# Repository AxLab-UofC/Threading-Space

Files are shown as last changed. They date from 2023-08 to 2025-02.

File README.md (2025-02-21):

# What is Threading Space?
Threading Space is a kinetic sculpture that explores how spatial perception can be transformed by dynamically and geometrically reconfiguring physical lines of thread. As the threads in motion interact, they become a hypnotic medium for three-dimensional patterns. Through a physical installation and an interactive GUI, Threading Space invites the audience to explore the potential of using swarm robots and line elements to create, morph, and interact with space.

# How does Threading Space Work?
The Core loop of Threading Space is:
- The Animation System calculates the posistions of the toios
- Using `motorVelocityTarget`, a new velocity is sent to the toios based on their current and target posistions/velocities
- The Visualization and GUI is updated based on the new expected and actual locations of the toios

# Core Animation System
The core animation system accepts two kinds of sequences:
- Uninteractive sequences, which output a 2D or 3D set of points based on a time `t` in milliseconds. There are two types of uninteractive sequences:
  - Smooth Sequences, which continously move for a period of time
  - Discrete Sequences, which consist of a set of frames. The path-finding mechanism automatically generates a Discrete sequence to move between two sets of points.
- Interactive sequences, which output a 2D or 3D set of points based on input from the user.

Using an input function, the core animation system allows for
- Queuing animations
- Pausing and resuming animations
- If an sequence is supposed to tangle, the animation can be played in reverse to automatically untangle.

# Files
- Main
  - `Path_Planning`: Runs the command to generate the path planning
  - `keyMousePressed`: Manages any key presses or mouse events, including debug mode
  - `Threading_Space`: Manages the main loop and defines all user-defined variables (i.e. number of toios, toggle MSI mode, etc.)
 
- The Animation System
  - `Animation_Manager`: Controls the flow between different animations; manages wait times if MSI
  - `anim_interactive`: Manages the Interactive animations: Each interactive animation has a set of variables that the user can change in real-time
  - `Anim_Cylinder`: An Interactive animation that has a cylinder at the top and on the bottom
  - `Anim_Line`:  An Interactive animation that has a line at the top and on the bottom
  - `Anim_Screensaver`:  Contains all the non-interactive animations, including the MSI-specific animation

- Visualization
  - `visual`: Manages the 3D positions of the cubes in the visualization. This allows for the visualization of threading space to be synced or independant from their physical locations.
  - `display`: Contains the 3d components that make up the threading space visualization
  - `gui`: Manages the interactive aspects of the GUI, (i.e. the buttons)
 
- Toio and OSC Management:
  - `Cube`:  Stores the Cube class, which abstracts away the lower level communication with the toios
  - `pair`: Stores the Pair class, which manages pairs of cubes at once
  - `MotorTargetVel`: Stores the `motorTargetVelocity` command which will use PID to smoothly follow a moving target
  - `oscRecieve`: Manages all received OSC messages
  - `oscSend`: Sends OSC Messages
  - `Battery_Management`: Manages the battery-life record, saved as csv file (if in MSI mode)

# MSI mode
Screensaver will operate at designated time-intervals (not constantly) 
- Toggle MSI mode by msi=true, see `Threading_Space`
- Operation times defined by int[] playTimes, see also `Threading_Space`
- MSI screensaver behavior defined in `Anim_Screensaver`: msi_screensaver()
  - To alter the MSI-specific sequence, see sequences defined within
- MSI battery collection files are saved by name and date. 
  - Format: YYYYMMDD_x for x files made

The Full Laptop-Toio Documnentation can be found [here](https://github.com/AxLab-UofC/Laptop-TOIO)

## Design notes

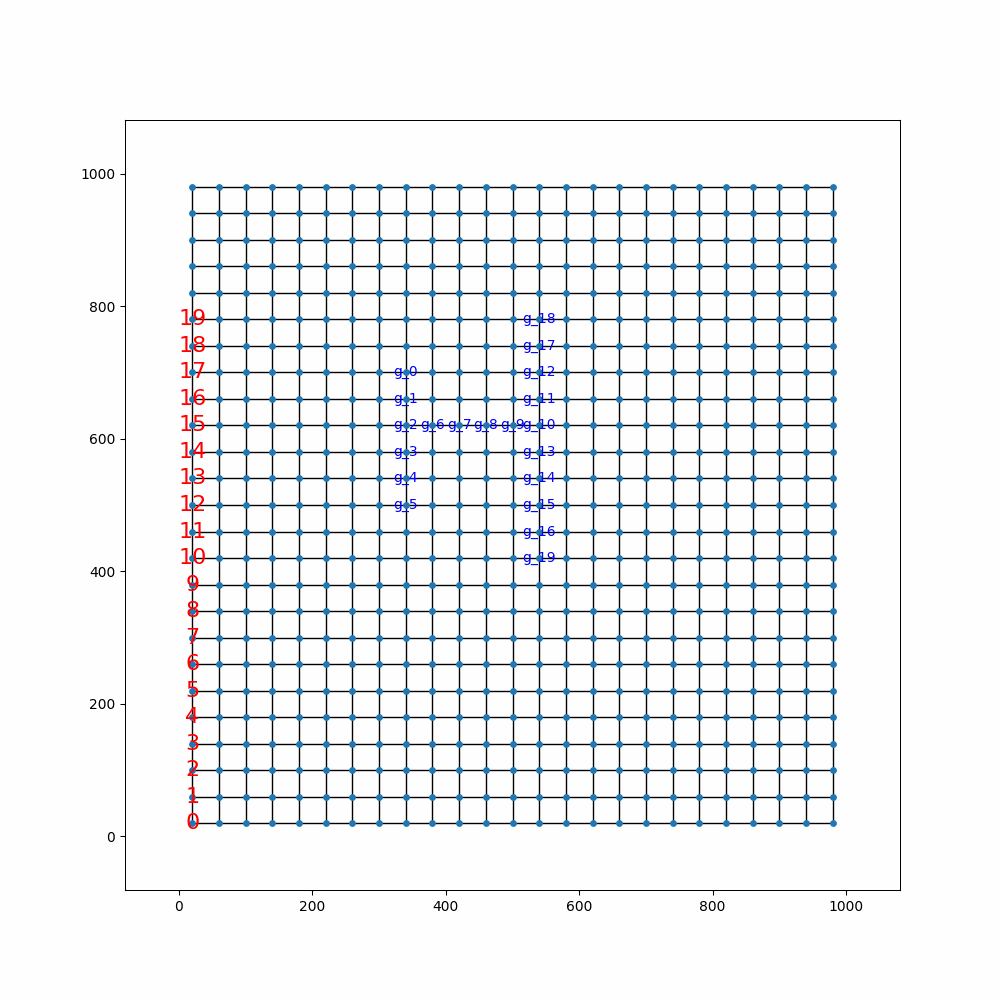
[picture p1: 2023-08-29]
general_planner_v1.0.1/toio_movement.gif

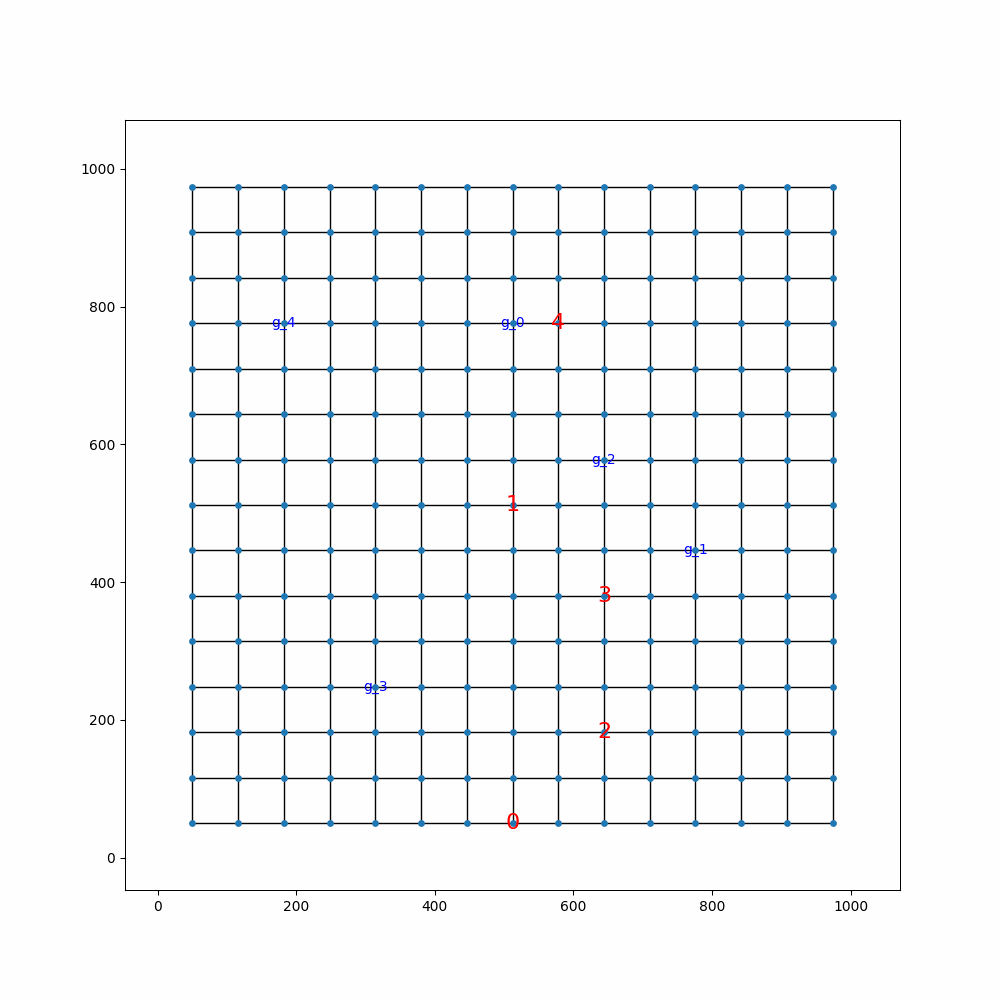
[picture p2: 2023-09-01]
general_planner_v1.0.1/movement.gif

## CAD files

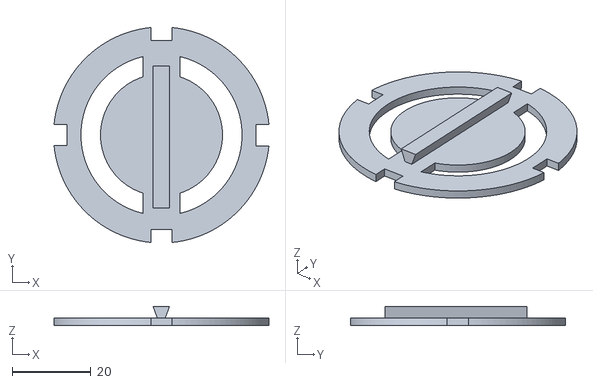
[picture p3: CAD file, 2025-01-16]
3D_print_files/final-lid-threading-space.stl
54.6 x 54.6 x 4.90

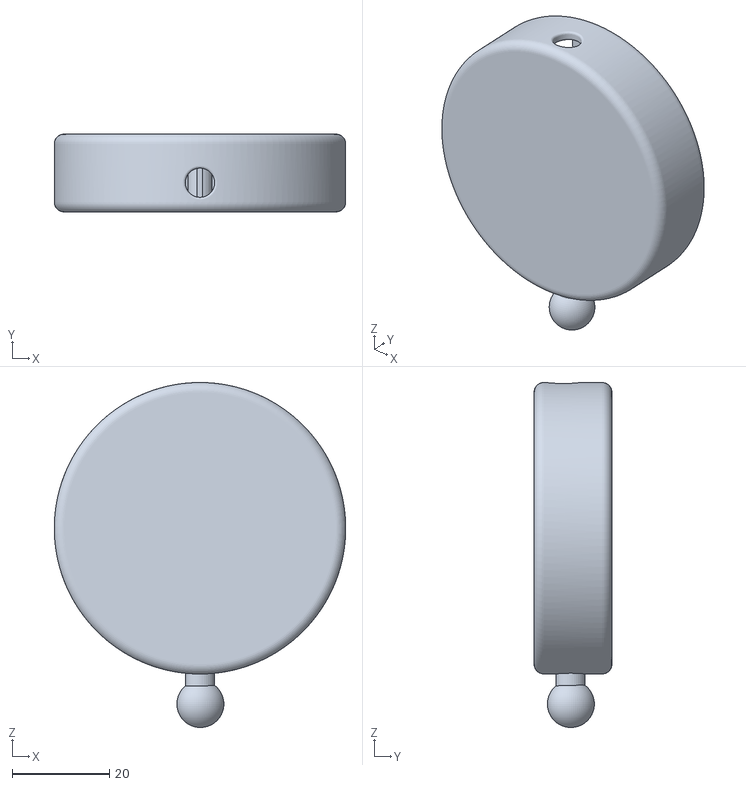
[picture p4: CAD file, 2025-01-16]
3D_print_files/reel_with_clasp-final-threading-space.stl
59.9 x 16.0 x 70.9

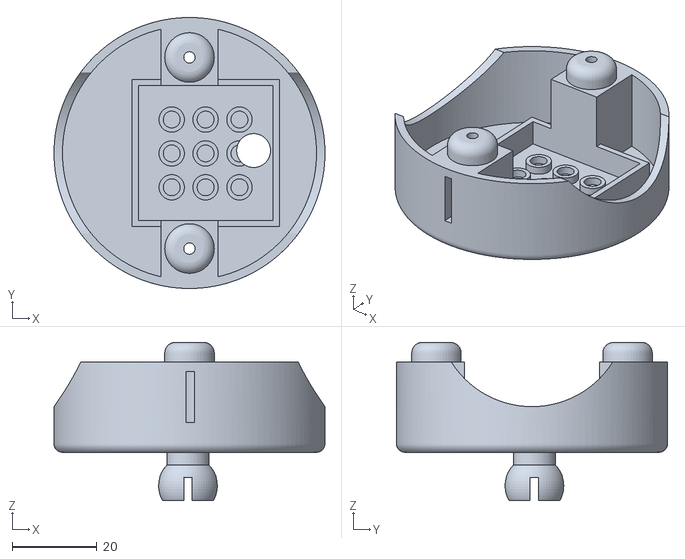
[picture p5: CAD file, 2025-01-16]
3D_print_files/toio_shell_-final-threading-space.stl
64.0 x 64.0 x 37.4

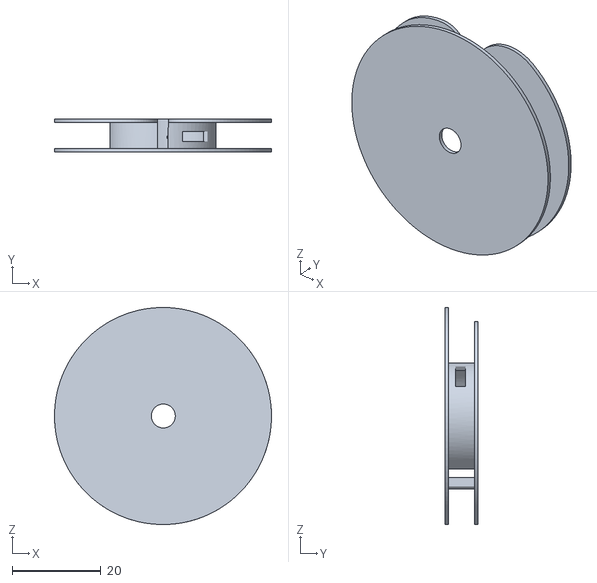
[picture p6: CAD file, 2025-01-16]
3D_print_files/scaled_inside_reel-with-rim-final-threading-space.stl
49.0 x 7.41 x 49.0

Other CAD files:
3D_print_files/fusion files/final-lid-threading-space.f3d
3D_print_files/fusion files/scaled_inside_reel-with-rim-final-threading-space.f3d

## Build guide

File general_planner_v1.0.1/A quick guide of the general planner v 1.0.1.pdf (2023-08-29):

# A quick guide of the general planner

v1.0.1 Update:
Now, the C++ planner can be run in the python notebook. No need to copy the map and agent files around.
The visualization code will now load the map and agent files that are the input to the C++ planner and visualize the planned paths.

The work is still ongoing. This is a quick guide about how to use the tool.
Required tools:
C++: the planner is a CMake project.
Python jupyter notebook or Google colab (an online python notebook environment)

How to use:
1. Generate maps and toio start and goal locations. This results in two files: a map file and an agent file.
The map file is a design of the "roads" in the planning space.
Example map file:

1000,1000,625,1200
0,20.0,20.0
1,20.0,60.0
2,20.0,100.0
3,20.0,140.0
4,20.0,180.0
5,20.0,220.0
6,20.0,260.0
7,20.0,300.0
8,20.0,340.0
9,20.0,380.0
623,980.0,940.0
624,980.0,980.0
0,1
0,25
1,2
1,26
2,3
2,27
3,4
3,28
4,5

The first line states: the x size of the planning space (1000), the y size of the planning space (1000), the number of vertices (waypoints that a toio can access) (625 vertices), the number of edges (1200).
Then the followed lines are the vertices (aka waypoints): vertex_id, x_coordinate, y_coordinate.
You can set the coordinates freely. But make sure that the waypoints are actually not blocked by any objects (e.g., walls).
Then the edge information lines: <vertex_id>, <connected_vertex_id>
For example, "0, 25" means the vertex with id 0 is connected to the vertex id 25.
The agent file states the start and the goal locations of toios:
For example,

The first line: <number_of_toios>
The followed lines: <toio_id>, <start_vertex_id>, <goal_vertex_id>
2. These two files are the input to the C++ planner.

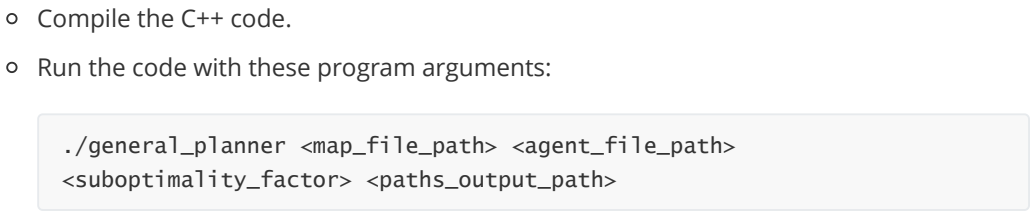
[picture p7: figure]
Compile the C++ code.; ./general_planner <map_file_path> <agent_file_path>; <suboptimality_factor> <paths_output_path>

Run the code with these program arguments:

<map_file_path>: the location of the map file.
<agent_file_path>: the location of the agent file.
<suboptimality_factor>: the parameter for focal search. You can simply put 5 in there. It trades the solution cost (the sum of path lengths) for runtime.
<paths_output_path>: where you want to output the path file.

20
0,0,217
1,1,216
2,2,215
3,3,214
4,4,213
5,5,212
6,6,240
7,7,265
8,8,290
9,9,315
10,10,340
11,11,341
12,12,342
13,13,339
14,14,338
15,15,337
16,16,336
17,17,343
18,18,344
19,19,335

3. Get the path file. The path file states the movements of toios in coordinates.

20,20,0 60,20,0 100,20,0 140,20,0 180,20,0 220,20,0 260,20,0 260,60,0 260,100,0 260,140,0 260,180,0 260,220,0 260,260,0 260,300,0 260,340,0 260,380,0 260,420,0 260,460,0 260,500,0 260,540,0 260,580,0 260,620,0 260,660,0 300,660,0 300,700,0 340,700,0
20,60,0 60,60,0 100,60,0 140,60,0 180,60,0 220,60,0 260,60,0 260,100,0 260,140,0 260,180,0 260,220,0 260,260,0 260,300,0 260,340,0 260,380,0 260,420,0 260,460,0 260,500,0 260,540,0 260,580,0 260,620,0 300,620,0 300,660,0 340,660,0
20,100,0 60,100,0 100,100,0 140,100,0 180,100,0 220,100,0 260,100,0 260,140,0 260,180,0 260,220,0 260,260,0 260,300,0 260,340,0 260,380,0 260,420,0 260,460,0 260,500,0 260,540,0 260,580,0 300,580,0 300,620,0 340,620,0
20,140,0 60,140,0 100,140,0 140,140,0 180,140,0 220,140,0 260,140,0 260,180,0 260,220,0 260,260,0 260,300,0 260,340,0 260,380,0 260,420,0 260,460,0 260,500,0 260,540,0 300,540,0 300,580,0 340,580,0
20,180,0 60,180,0 100,180,0 140,180,0 180,180,0 220,180,0 260,180,0 260,220,0 260,260,0 260,300,0 260,340,0 260,380,0 260,420,0 260,460,0 260,500,0 300,500,0 300,540,0 340,540,0
20,220,0 60,220,0 100,220,0 140,220,0 180,220,0 220,220,0 260,220,0 300,220,0 340,220,0 340,260,0 340,300,0 340,340,0 340,380,0 340,420,0 340,460,0 340,500,0
20,260,0 60,260,0 100,260,0 140,260,0 180,260,0 220,260,0 260,260,0 300,260,0 340,260,0 380,260,0 380,300,0 380,340,0 380,380,0 380,420,0 380,460,0 380,500,0 380,540,0 380,580,0 380,620,0
20,300,0 60,300,0 100,300,0 140,300,0 180,300,0 220,300,0 260,300,0 300,300,0 340,300,0 380,300,0 420,300,0 420,340,0 420,380,0 420,420,0 420,460,0 420,500,0 420,540,0 420,580,0 420,620,0
20,340,0 60,340,0 100,340,0 140,340,0 180,340,0 220,340,0 260,340,0 300,340,0 300,380,0 300,420,0 340,420,0 380,420,0 380,460,0 380,500,0 380,540,0 380,580,0 420,580,0 460,580,0 460,620,0
20,380,0 60,380,0 100,380,0 140,380,0 180,380,0 220,380,0 260,380,0 300,380,0 300,420,0 300,460,0 340,460,0 380,460,0 420,460,0 420,500,0 420,540,0 460,540,0 500,540,0 500,580,0 500,620,0
20,420,0 60,420,0 100,420,0 140,420,0 180,420,0 220,420,0 260,420,0 300,420,0 300,460,0 300,500,0 340,500,0 380,500,0 420,500,0 420,540,0 420,580,0 460,580,0 500,580,0 500,620,0 540,620,0
20,460,0 60,460,0 100,460,0 140,460,0 180,460,0 220,460,0 260,460,0 300,460,0 300,500,0 300,540,0 340,540,0 380,540,0 380,580,0 420,580,0 460,580,0 500,580,0 500,620,0 540,620,0 540,660,0
20,500,0 60,500,0 100,500,0 140,500,0 180,500,0 220,500,0 260,500,0 300,500,0 340,500,0 380,500,0 420,500,0 460,500,0 500,500,0 500,540,0 500,580,0 500,620,0 540,620,0 540,660,0 540,700,0
20,540,0 60,540,0 100,540,0 140,540,0 180,540,0 220,540,0 260,540,0 300,540,0 340,540,0 380,540,0 420,540,0 460,540,0 500,540,0 500,580,0 500,620,0 540,620,0 540,580,0
20,580,0 60,580,0 100,580,0 140,580,0 180,580,0 220,580,0 260,580,0 300,580,0 340,580,0 380,580,0 420,580,0 460,580,0 500,580,0 540,580,0 540,540,0
20,620,0 60,620,0 100,620,0 140,620,0 180,620,0 220,620,0 260,620,0 300,620,0 340,620,0 380,620,0 420,620,0 460,620,0 500,620,0 540,620,0 540,580,0 580,580,0 580,540,0 580,500,0 540,500,0
20,660,0 60,660,0 100,660,0 140,660,0 180,660,0 220,660,0 260,660,0 300,660,0 340,660,0 380,660,0 420,660,0 460,660,0 460,620,0 460,580,0 460,540,0 500,540,0 500,500,0 540,500,0 540,460,0

Each line is the movement of a toio in coordinates (x,y,z). The z-axis movement is not implemented at this moment.
The toio stays at the goal location once it reaches the location.

# Walkthrough of an example:

1. Open the python notebook ("map_generator_and_visulization.ipynb")
2. Run the library import block

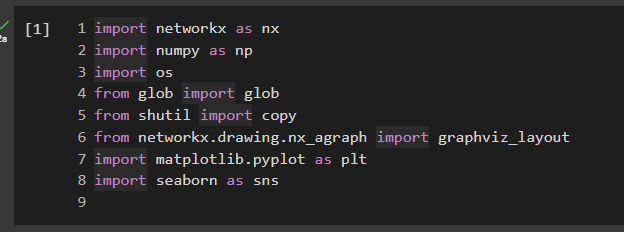
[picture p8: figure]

3. Then move on to the code for generating a grid general map.

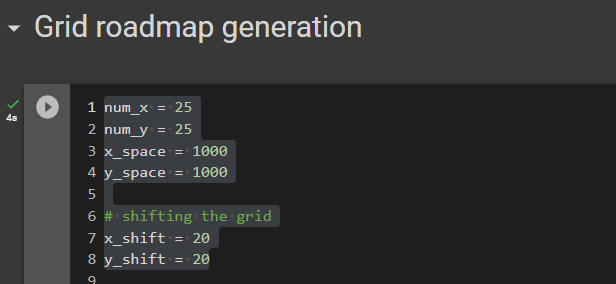
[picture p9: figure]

You only need to change these parameters. num_x: how many vertices are in the x-axis num_y: how many vertices are in the y-axis x_space: the x size of the map

20,700,0 60,700,0 100,700,0 140,700,0 180,700,0 220,700,0 260,700,0 300,700,0 340,700,0 380,700,0 420,700,0 460,700,0 500,700,0 540,700,0 540,740,0
20,740,0 60,740,0 100,740,0 140,740,0 180,740,0 220,740,0 260,740,0 300,740,0 340,740,0 380,740,0 420,740,0 460,740,0 500,740,0 540,740,0 540,780,0
20,780,0 60,780,0 100,780,0 140,780,0 180,780,0 220,780,0 260,780,0 300,780,0 300,740,0 300,700,0 340,700,0 380,700,0 420,700,0 460,700,0 460,660,0 460,620,0 460,580,0 460,540,0 500,540,0 500,500,0 500,460,0 500,420,0 540,420,0 y_space: the y size of the map
x_shift: it shifts the x coordinates of all vertices. y_shift: it shifts the y coordinates of all vertices.

Run the code, and you will see this picture output.

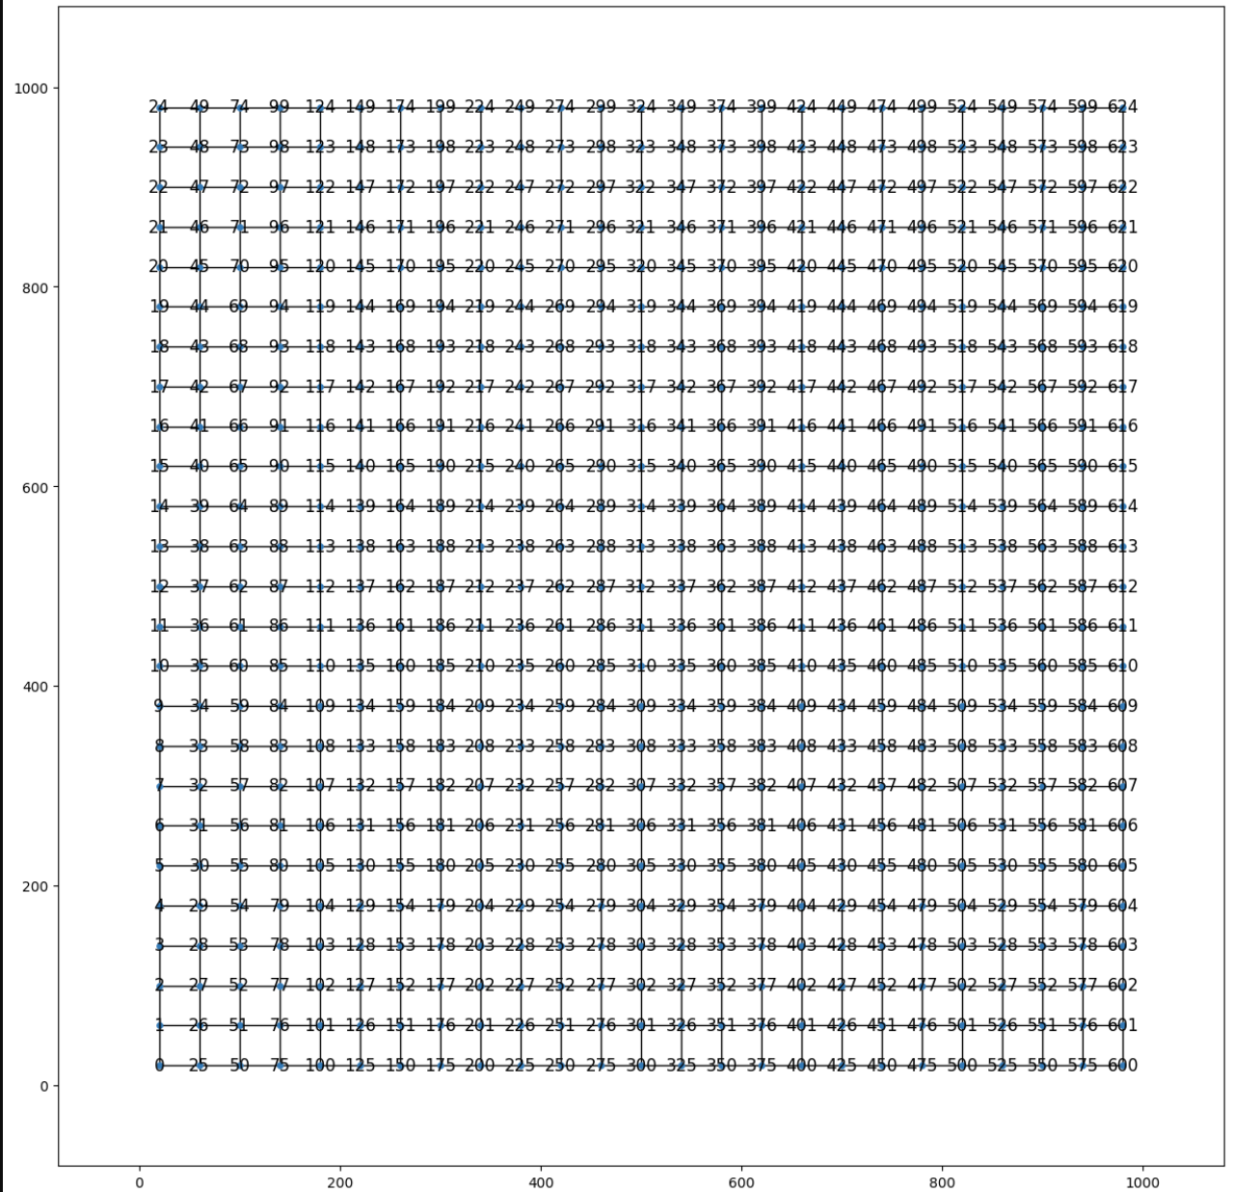
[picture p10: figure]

This is the grid "roadmap" generated by the code. Each vertex is the waypoint where the toio can be on, and each vertex is labelled with its vertex id.
The display of the vertex id can be helpful, if you want to write down the start and goal locations of toios mannually.

After running this block of code, it generates a map file "grid_map_x_x_x.txt" in the "toio_map_example" folder.
This is the map file that you need for using the C++ planner.
4. Generate an agent file.
This block of code generates one agent file with random start and goal locations.

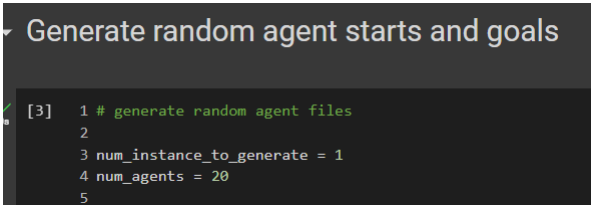
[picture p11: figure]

num_instance_to_generate: how many agent files will be generated. num_agents: how many toios are used.

You can use this block of code to generate a customized agent file.

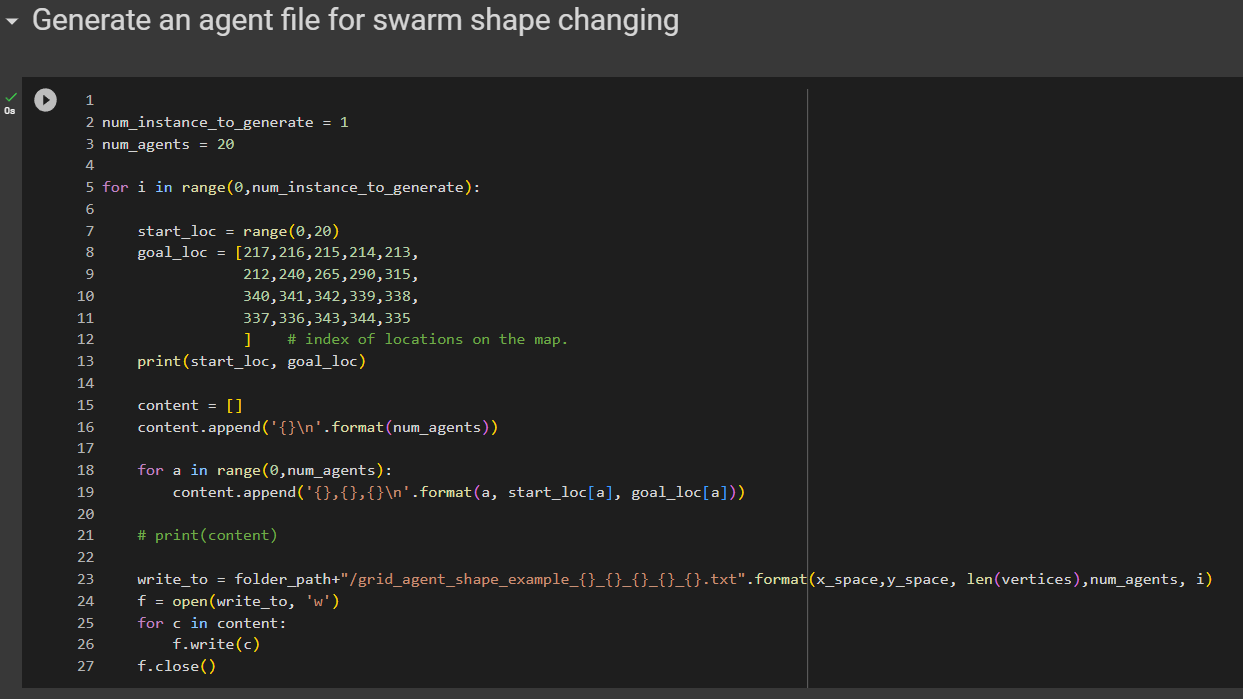
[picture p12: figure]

start_loc (line 7): the start vertex id for each agent.

goal_loc (line 8): the goal vertex id for each agent.
You can look at the map image generated in the previous step to pick the start and goal locations.
write_to (line 23): the path to the agent file. In this case, you will find an agent file in the "toio_map_examples" folder.
5. Compile the C++ planner and go to this block.

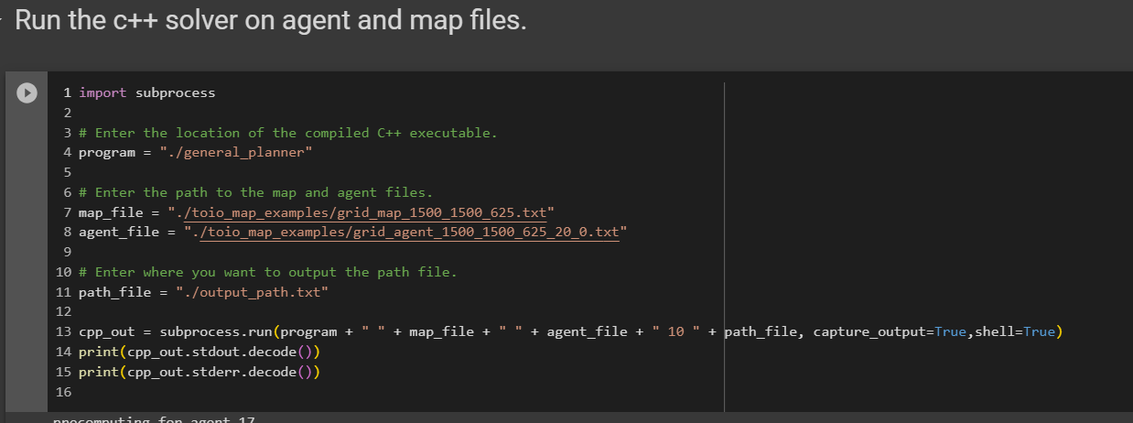
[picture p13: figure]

program: enter the path to the compiled C++ planner executable. map_file: which map file you want to load for planning. agent_file: which agent file you want to load for planning. path_file: where to output the result paths.

You can run the planner by just running this block of code.

6. Then just run the visualization code.
Now the visualization code will visualize the map and the movements that are just planned by the C++ planner.
The code reads the paths that are stored in "map_file", "agent_file", and "path_file" in the running C++ planner code block (the inputs to the planner and the output from the planner.).

Example movement:
If this git doesn't move in this document, check toio_movement.gif in the folder.


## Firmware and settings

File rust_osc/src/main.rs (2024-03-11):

extern crate getopts;
use btleplug::api::CharPropFlags;
use btleplug::api::{
    Central, CentralEvent, Characteristic, Manager as _, Peripheral, ScanFilter, WriteType,
};
use getopts::Options;

use btleplug::platform::Manager;
use futures::stream::StreamExt;
use rosc::encoder;
use rosc::{OscMessage, OscPacket, OscType};
use std::collections::HashMap;
use std::error::Error;
use std::sync::{Arc, Mutex};
use std::time::Duration;
use std::{env, net::SocketAddr};
use tokio::time;
use tokio::{net::UdpSocket, sync::mpsc};
use uuid::Uuid;

//#[macro_use]
extern crate log;

//characteristic of interest
const TOIO_SERVICE_UUID:            Uuid = Uuid::from_u128(0x10B20100_5B3B_4571_9508_CF3EFCD7BBAE);
const POSITION_CHARACTERISTIC_UUID: Uuid = Uuid::from_u128(0x10B20101_5B3B_4571_9508_CF3EFCD7BBAE);
const MOTOR_CHARACTERISTIC_UUID:    Uuid = Uuid::from_u128(0x10B20102_5B3B_4571_9508_CF3EFCD7BBAE);
const LIGHT_CHARACTERISTIC_UUID:    Uuid = Uuid::from_u128(0x10B20103_5B3B_4571_9508_CF3EFCD7BBAE);
const SOUND_CHARACTERISTIC_UUID:    Uuid = Uuid::from_u128(0x10B20104_5B3B_4571_9508_CF3EFCD7BBAE);
const MOTION_CHARACTERISTIC_UUID:   Uuid = Uuid::from_u128(0x10B20106_5B3B_4571_9508_CF3EFCD7BBAE);
const BUTTON_CHARACTERISTIC_UUID:   Uuid = Uuid::from_u128(0x10B20107_5B3B_4571_9508_CF3EFCD7BBAE);
const BATTERY_CHARACTERISTIC_UUID:  Uuid = Uuid::from_u128(0x10B20108_5B3B_4571_9508_CF3EFCD7BBAE);

fn print_usage(program: &str, opts: Options) {
    let brief = format!("Usage: {} FILE [options]", program);
    print!("{}", opts.usage(&brief));
}

fn print_toio_connected(toio_connected: i32){
    if toio_connected == 1 {println!("1 peripheral connected");}
    else {println!("{} peripherals connected", toio_connected);}
}

fn return_toio_id(name: &str) -> &str{
    //list of toio ids
    const IDARR : [&str; 193] = [
        "Individual ID",  //TOIO Num
        "0",  // #1
        "j1c",  // #2
        "r81",  // #3
        "26E",  // #4
        "76t",  // #5
        "broken",  // #6
        "k5k",  // #7
        "h41",  // #8
        "0",  // #9
        "0",  // #10
        "0",  // #11
        "Q3A",  // #12
        "03a",  // #13
        "0",  // #14
        "K0m",  // #15
        "0",  // #16
        "0",  // #17
        "p8B",  // #18
        "91B",  // #19
        "p75",  // #20
        "G1E",  // #21
        "k2L",  // #22
        "b5p",  // #23
        "J6C",  // #24
        "0",  // #25
        "b8T",  // #26
        "b6A",  // #27
        "01c",  // #28
        "0",  // #29
        "0",  // #30
        "E2N",  // #31
        "G7t",  // #32
        "L6T",  // #33
        "C0E",  // #34
        "t79",  // #35
        "J6k",  // #36
        "d6f",  // #37
        "0",  // #38
        "M75",  // #39
        "310",  // #40
        "M5p",  // #41
        "A4a",  // #42
        "M9J",  // #43
        "i01",  // #44
        "T5m",  // #45
        "j1G",  // #46
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
    ];
    match name.parse::<i32>() {
        Ok(n) => {
            let name = IDARR[n as usize];
            return name;
        },
        Err(_e) => {
            panic!("Error while reading the names");
        }
      }
}                

#[tokio::main]
async fn main() -> Result<(), Box<dyn Error>> {
    env_logger::init();

    let mut toio_connected = 0;
    let mut verbose = false;
    let mut search = false;
    let mut ordered = false;
    let mut ordernum = 0;

    //read command line arguments
    let args: Vec<String> = env::args().collect();
    let program = args[0].clone();

    let mut opts = Options::new();
    opts.optopt("p", "port", "set receiving port", "PORT_NUMBER");
    opts.optopt("r", "remote", "set remote port", "IP:PORT_NUMBER");
    opts.optopt("i", "host_id", "set host id number", "ID_NUMBER");
    opts.optopt("n", "names", "connect to those cubes only", "AAA,BBB,CCC");
    opts.optopt("a", "axlab_id", "connect to those cubes only (#1, #2, #3)", "1,2,3");
    opts.optflag("h", "help", "print this help menu");
    opts.optflag("v", "verbose", "print more connection details");
    opts.optflag("s", "search", "search for toios without specifying IDs");
    opts.optflag("o", "ordered", "search for toios in order of IDs");

    let matches = match opts.parse(&args[1..]) {
        Ok(m) => { m }
        Err(f) => { panic!("{}",f.to_string())}
    };
    if matches.opt_present("h") {
        print_usage(&program, opts);
        return Ok(());
    }
    if matches.opt_present("v") {
        verbose = true;
    }
    if matches.opt_present("s") {
        search = true;
    }

    let port_number = matches.opt_str("p").unwrap_or("3334".to_string());
    let listening_address = format!("0.0.0.0:{}", port_number);

    //this will be filled with the names to connect to *if needed*
    let possible_names = {
        let mut res = Vec::new();
        match matches.opt_str("n") {
            Some(names) => {
                for part in names.split(",") {
                    if part.len() == 3 {
                        res.push(format!("toio Core Cube-{}", part));
                    } else {
                        panic!("Error while reading the names");
                    }
                }
            },
            None => {}
        }
        match matches.opt_str("a") {
            Some(names) => {
                for part in names.split(",") {
                    res.push(format!("toio Core Cube-{}", return_toio_id(part)));
                }
            },
            None => {}
        }

        if !search && res.len() == 0 {
            panic!("Toio IDs must be specified unless in search mode");
        }

        if res.len() > 0 {
            ordernum = res.len();
            Some(res)
        } else {
            None
        }
    };

    if matches.opt_present("o") {
        ordered = true;
        ordernum = 1;
    }

    //the ID/addresses of the cubes
    //let addresses: Arc<Mutex<Vec<BDAddr>>> = Arc::new(Mutex::new(Vec::new()));
    let uuids: Arc<Mutex<Vec<btleplug::platform::PeripheralId>>> = Arc::new(Mutex::new(Vec::new()));
    let senders: Arc<Mutex<HashMap<btleplug::platform::PeripheralId, mpsc::Sender<OscMessage>>>> =
        Arc::new(Mutex::new(HashMap::new()));

    //OSC listening on port 3334
    let sock = UdpSocket::bind((listening_address).parse::<SocketAddr>().unwrap()).await?;
    println!("OSC listening on port {}", port_number);

    let r = Arc::new(sock);
    let s = r.clone();
    let (tx, mut rx) = mpsc::channel::<(Vec<u8>, SocketAddr)>(1_000);

    //Where to send packets
    let remote = matches.opt_str("r").unwrap_or("127.0.0.1:3333".to_string());
    let remote_read = remote.parse::<SocketAddr>();
    let remote_addr = if remote_read.is_ok() {
        remote_read.unwrap()
    } else {
        eprintln!(
            "Remote address {} is wrongly formatted, use IP:PORT (127.0.0.1:3333)",
            remote
        );
        return Ok(());
    };

    let host_id = matches
        .opt_str("i")
        .unwrap_or("0".to_string())
        .parse::<i32>()
        .unwrap_or(0);
    println!(
        "Sending messages to {} prefixed by {}",
        remote_addr, host_id
    );

    //Send OSC
    tokio::spawn(async move {
        //just one channel
        while let Some((bytes, addr)) = rx.recv().await {
            s.send_to(&bytes, &addr).await.unwrap();
        }
    });

    //Receive OSC
    let mut buf = [0; 1024];
    //let addresses2 = addresses.clone();
    let uuids2 = uuids.clone();
    let senders2 = senders.clone();

    tokio::spawn(async move {
        while let Ok((len, addr)) = r.recv_from(&mut buf).await {
            println!("{:?} bytes received from {:?}", len, addr);
            let packet = rosc::decoder::decode(&buf[..len]).unwrap();
            match packet {
                OscPacket::Message(msg) => {
                    if msg.args.len() > 0 {
                        let mut marg = 0;
                        if let OscType::Int(i) = msg.args[0] {
                            marg = i;
                        }
                        println!("Got a message for {}", marg);

                        // find the address
                        let maybe_uuid = {
                            let storage_uuid = uuids2.lock().unwrap();
                            if storage_uuid.len() > marg as usize {
                                Some(storage_uuid[marg as usize].clone())
                            } else {
                                None
                            }
                        };
                        if let Some(uuid) = maybe_uuid {
                            //try to get the channel and not breaking everything
                            let sender = {
                                let sends = senders2.lock().unwrap();
                                sends.get(&uuid).map(|p| p.clone())
                                //we drop the lock here because we *clone*
                            };
                            if let Some(channel) = sender {
                                println!("Sending to...");
                                channel.send(msg).await.unwrap();
                            }
                        }
                    }
                }
                OscPacket::Bundle(bundle) => {
                    println!("OSC Bundle: {:?}", bundle);
                }
            }
        }
    });

    let manager = Manager::new().await?;

    println!("Found Manager: {:?}", manager);
    // get the first bluetooth adapter
    // connect to the adapter
    let adapters = manager.adapters().await.unwrap();
    println!("Found Adapter: ");
    for adapter in adapters.iter() {
        println!("Found Adapter: {}", adapter.adapter_info().await?);
    }

    let central = adapters.into_iter().nth(0).unwrap();

    //get the events from the central
    let mut events = central.events().await?;

    // start scanning for devices
    central
        .start_scan(ScanFilter {
            services: vec![TOIO_SERVICE_UUID],
        })
        .await?;

    if verbose {
        println!("Scanning for BTLE events on {:?}...",central);
    }
    else {
        println!("Scanning for BTLE events...");
    }  

    //Scan all the time
    while let Some(event) = events.next().await {
        //println!("event... {:?}", event);
        let mut device_candidate: Option<btleplug::platform::PeripheralId> = None;
        //Sometimes we miss the discovered event, so react on the DeviceUpdated as well
        match event {
            CentralEvent::DeviceUpdated(bd_addr) => {
                device_candidate = Some(bd_addr);
            }
            CentralEvent::DeviceDiscovered(bd_addr) => {
                device_candidate = Some(bd_addr);
            }
            CentralEvent::DeviceDisconnected(bd_addr) => {
                println!("DeviceDisconnected: {:?}", bd_addr);
                toio_connected -= 1;
                print_toio_connected(toio_connected);
            }
            _ => {}
        }

        
        //
        if let Some(bd_addr) = device_candidate {
            let peripheral = central.peripheral(&bd_addr).await.unwrap();

            let properties = peripheral.properties().await?.unwrap();
            let local_name = properties.local_name.unwrap_or("".to_string());

            let services = properties.services;
            let should_connect = if let Some(names) = &possible_names {
                if ordernum > names.len() {
                    ordernum -= 1;
                }
                names[0 ..ordernum].contains(&local_name)
            } else {
                services.contains(&TOIO_SERVICE_UUID)
            };


            //if (services.contains(&TOIO_SERVICE_UUID)) || possible_names.contains(&local_name)  {
            if should_connect {
                if ordered {
                    ordernum += 1;
                }
                //we kave a toio cube!
                let tx3 = tx.clone();
                if !(peripheral.is_connected().await?) {
                    println!("Device Connected: {}", local_name);
                    toio_connected  += 1;
                    print_toio_connected(toio_connected);

                    // Connect if we aren't already connected.
                    if let Err(err) = peripheral.connect().await {
                        eprintln!("Error connecting to peripheral, skipping: {}", err);
                        continue;
                    }
                    time::sleep(Duration::from_millis(200)).await;
                    // We should be connected now
                    let peripheral_id = peripheral.id();
                    if verbose {
                        println!("connecting with Peripheral ID: {:?}", peripheral_id);
                    }

                    //find the id for this cube
                    //let mut addr = addresses.lock().unwrap();
                    let mut storage_uuid = uuids.lock().unwrap();

                    //do we already know that address?
                    let id = if let Some(index) =
                        storage_uuid.iter().position(|a| a == &peripheral_id)
                    {
                        index
                    } else {
                        //no, add it to the list
                        storage_uuid.push(peripheral_id.clone());
                        storage_uuid.len() - 1
                    };
                    //get rid of the mutex lock
                    drop(storage_uuid);
                    //println!("Connecting to Cube {} address is {}", id, address);

                    //creating the channels
                    let (tx, mut rx) = mpsc::channel::<OscMessage>(1_000);
                    //saving one end to allow to receive OSC
                    let mut sends = senders.lock().unwrap();
                    sends.insert(peripheral_id, tx);
                    drop(sends);

                    let id2 = id;
                    let p2 = peripheral.clone();
                    tokio::spawn(async move {
                        while let Some(message) = rx.recv().await {
                            println!("Received {:?} for cube {}", message, id2);
                            match message.addr.as_ref() {
                                "/motorbasic" => {
                                    if message.args.len() == 5 {
                                        //we should have 5 args
                                        println!("Message received");
                                        let mut marg = [0; 5];
                                        for k in 0..5 {
                                            if let OscType::Int(i) = message.args[k] {
                                                marg[k] = i;
                                            }
                                        }

                                        let characteristic = Characteristic {
                                            uuid: MOTOR_CHARACTERISTIC_UUID,
                                            service_uuid: TOIO_SERVICE_UUID,
                                            properties: CharPropFlags::WRITE_WITHOUT_RESPONSE,
                                        };
                                        let cmd = vec![
                                            0x01,                 //motor
                                            0x01,                 //left
                                            marg[1].abs() as u8,  //forwards or backwards
                                            marg[2].abs() as u8,  //speed
                                            0x02,                 //right
                                            marg[3].abs() as u8,  //forwards or backwards
                                            marg[4].abs() as u8,  //speed
                                        ];
                                        p2.write(&characteristic, &cmd, WriteType::WithoutResponse)
                                            .await
                                            .unwrap();
                                    } else {
                                        //error
                                    }
                                }
                                "/motorduration" => {
                                    if message.args.len() == 6 {
                                        //we should have 5 args
                                        println!("Message received");
                                        let mut marg = [0; 6];
                                        for k in 0..6 {
                                            if let OscType::Int(i) = message.args[k] {
                                                marg[k] = i;
                                            }
                                        }
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

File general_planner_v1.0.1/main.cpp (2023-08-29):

// The general path planner for the collaboration with AxLab.
// This is an ongoing work. License will be added.
// Author: Yi Zheng, yzheng63@usc.edu

#include <iostream>
#include <boost/program_options.hpp>
#include <boost/tokenizer.hpp>

#include "CBS.h"

using namespace std;

int main(int argc, char** argv) {

    // loading program parameters.

    string map_file = argv[1];
    string agent_file = argv[2];
    int w_value = stoi(argv[3]);
    string output_file = argv[4];

    Instance * ins = new Instance();
    ins->load_map(map_file);
    ins->load_agents(agent_file);
//    ins->load_map("../examples/grid_map_1000_1000_625.txt");
//    ins->load_agents("../examples/grid_agent_shape_example_1000_1000_625_20_0.txt");

    CBS * planner = new CBS(ins);
    planner->debug_print = false;

    auto plan = planner->find_solution(w_value);

    if (plan.empty()) {
        cout << "No solution." << endl;
        return 0;
    }

    // save the paths
//    int max_length = 0;

//    for (int i = 0; i < ins->num_agent; i++) {
//        if (plan[i].size() >= max_length) {
//            max_length = plan[i].size();
//        }
//    }
    ofstream paths_output;
    paths_output.open(output_file);
    for (int i = 0; i < ins->num_agent; i++) {
        for (auto loc : plan[i]) {
            paths_output << get<0>(loc) << "," << get<1>(loc) << "," << get<2>(loc) << " ";
        }
        paths_output << endl;
    }
    paths_output.close();

    return 0;
}

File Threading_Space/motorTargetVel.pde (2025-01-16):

boolean motorTargetVelocity(int id, int x, int y, float vx, float vy) {
  if (!cubes[id].onFloor) {
    x = xmax - x + xmin;
    vx = -vx;
  }

  if (cubes[id].isActive) {
    int left = 0;
    int right = 0;
    float angleToTarget = atan2(y - cubes[id].y, x - cubes[id].x);

    float thisAngle = cubes[id].theta * PI / 180;
    float diffAngle = thisAngle - angleToTarget;
    if (diffAngle > PI) diffAngle -= TWO_PI;
    if (diffAngle < -PI) diffAngle += TWO_PI;

    // Add a small dead zone to prevent jitter
    if (abs(diffAngle) < 0.1) diffAngle = 0;

    if (abs(diffAngle) > HALF_PI) {
      float frac = cos(diffAngle);
      if (diffAngle > 0) {
        left = floor(maxMotorSpeed * pow(frac, 2));
        right = maxMotorSpeed;
      } else {
        left = maxMotorSpeed;
        right = floor(maxMotorSpeed * pow(frac, 2));
      }
    } else {
      float frac = -cos(diffAngle);
      if (diffAngle > 0) {
        left = -floor(maxMotorSpeed * pow(frac, 2));
        right = -maxMotorSpeed;
      } else {
        left = -maxMotorSpeed;
        right = -floor(maxMotorSpeed * pow(frac, 2));
      }
    }
    int[] lr = {left, right};

    float velIntegrate = sqrt(sq(vx) + sq(vy));
    float aimMotSpeed = velIntegrate / 2.0; // variable that decide how much velocity mapping affect the final motor speed (2.0)
    float aa = (lr[0] < 0) ? -aimMotSpeed : aimMotSpeed;

    float dd = cubes[id].distance(x, y) / 100; //slow down proportionally based on the distance from the target (100)
    dd = min(dd, 1);

    float targetLeft = constrain(aa + (lr[0] * dd), -maxMotorSpeed, maxMotorSpeed);
    float targetRight = constrain(aa + (lr[1] * dd), -maxMotorSpeed, maxMotorSpeed);

    // Apply smoothing to motor speeds
    float left_ = 0;
    float right_ = 0;
    float smoothFactor = 0;
    left_ = smoothFactor * left_ + (1 - smoothFactor) * targetLeft;
    right_ = smoothFactor * right_ + (1 - smoothFactor) * targetRight;

    // Update motor with smoothed values
    int duration = 100;
    motorDuration(id, (int)left_, (int)right_, duration);
  }
  return false;
}

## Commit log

2023-08-18 Transfered Files From Laptop-Toio
    [cubes.csv]
2023-08-19 Need to Add AimCube Velocity
2023-08-19 added Threading Space Folder
2023-08-19 Fixed errors with smooth animation get()
    [Animation_Manager.pde]
2023-08-19 testing to add target velocity
2023-08-19 adding target velocity to cylinder animation
2023-08-20 Velocity visualization added to cylinder animation.
2023-08-21 motorTargetVel first push
2023-08-21 Motor Target First Attempt
2023-08-21 MotorTargetVel Tested and Adjusted
2023-08-22 Combined Velocity Target with Smooth Animations
2023-08-25 Removed rust_bridge folder and fixed IP
    [cubes.csv]
2023-08-30 reset fnction and mode UI
    [Anim_Cylinder.pde, Threading_Space.pde, gui.pde]
2023-08-31 Path planning fixed for Threading Space
    [Animation_Manager.pde, Path_Planning.pde, keyMousePressed.pde]
2023-08-31 SOlved Pathfinding to animation
    [Anim_Cylinder.pde, Animation_Manager.pde, Threading_Space.pde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]
2023-09-01 maybe fixing slider dissapearance issue?
    [Threading_Space.pde]
2023-09-02 Replaced Cross to Wave
    [Animation_Manager.pde, Path_Planning.pde, Threading_Space.pde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]
2023-09-05 Flipped in x-axis instead of y
    [Anim_Cylinder.pde, Anim_Line.pde, Animation_Manager.pde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]
2023-09-05 Revert "Flipped in x-axis instead of y"
    This reverts commit fd4b09c4a3eb00927c1ab6f2b1da18e9d4656ffe.
    [Anim_Cylinder.pde, Anim_Line.pde, Animation_Manager.pde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]
2024-06-20 Major jitters fixed, minor jitters remain
    [Cube.pde, Threading_Space.pde]
2024-06-20 Major jitters resolved, minor jitters remain. Uncommented velocityTarget() calls in pair.pde
    [Path_Planning.pde, Threading_Space.pde, motorTargetVel.pde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]
2024-11-14 Jitters Solved!
2025-01-16 Added battery testing infrastructure, new gitignore stuff
2025-02-21 Added battery management, fixed bugs with restart, etc... (msi)
    [battery_report_20250212.csv, battery_report_20250212_0.csv, battery_report_20250212_1.csv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]
